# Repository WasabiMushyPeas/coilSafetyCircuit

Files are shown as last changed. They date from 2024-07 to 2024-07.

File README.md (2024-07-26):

# Coil Safety Circuit :electric_plug:

## Introduction :wave:
This safety circuit uses an ESP32 C6 to detect temperature fluctuations or moisture build up on an electromagnet. It can shut off the coils via relay if needed. The ESP32 also hosts a network and webpage to monitor the status of the coils and set the temperature shut off threshold.

## Specifications :clipboard:
- **Power Supply:** USB-C cable to micro controller
- **Max Continuous Coil Power (Each coil):** 65v 5A
- **Max Burst Coil Power:** 65v 35A
- **Pump Power:** 12v 5A
- **Temperature Sensors:** 4 thermistors with an accuracy of ±0.25°C

## Webpage :computer:

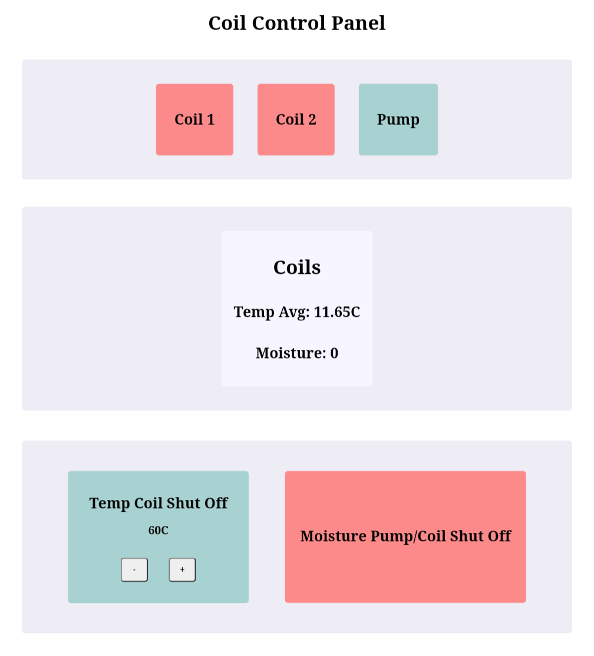
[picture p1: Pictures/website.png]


This picture shows the default settings and appearance of the ESP32 webpage. The user can change the state of the coils and the pump with the three buttons in the top row. If a button is coloured red then that setting or component is off (no relay is open). All coils are off by default and the pump remains on. The user can also turn on and off temperature and moisture shut off with the buttons on the bottom row. It is also possible to change the temperature shut off threshold by clicking the plus or minus buttons on the temperature shut off button until the desired temperature is shown. The middle row show the current temperature average of all the thermistors and whether the moisture sensors are detecting water (0 being to water 1 being water). If the middle row cell is clicked or hovered over it displays more information about the sensors.

:warning: **Warning:** if the ESP32 crashes or loses power everything will be reset to default settings. :warning:

- **Default Settings:** Coils 1 and 2 are off, the pump is on, temperature shut off is on, moisture shut off is off, and the temperature shut off threshold is 60°C.

## Network :satellite:

The webpage can be accessed by connect to the ESP32 network and typing the IP address of the ESP32 into a web browser. The IP address is displayed on the serial monitor when the ESP32 is booting up.

The network name is:
```
ESP32-Access-Point
```

The password is:
```
rydberg12
```

The default IP address is:

```
192.168.4.1
```

## LED Indicators :bulb:
- **Green LED:** Normal operation and coils are off
- **Red LED:** Temperature shut off is active
- **Orange LED:** Moisture shut off is active
- **Blue LED:** Coils are on
- **No LED:** Something is very wrong with the ESP32

## Parts List :moneybag:

| Part | Quantity | Price  |
| --- | --- | --- |
| [ESP32 C6 DEV](https://www.digikey.com/en/products/detail/espressif-systems/ESP32-C6-DEVKITM-1-N4/18667011) | 1 | $8.00  |
| [Thermistor](https://www.digikey.com/en/products/detail/adafruit-industries-llc/4890/13982731) | 4 | $4.75  |
| [Water Sensor](https://www.digikey.com/en/products/detail/adafruit-industries-llc/4965/14302510) | 2 | $3.90  |
| [Coil Relay](https://www.digikey.com/en/products/detail/american-zettler/AZDC007-1AE-12D/22050421) | 2 | $11.78 |
| [Pump Relay](https://www.digikey.com/en/products/detail/american-zettler/AZ943-1CH-12DE/12171590) | 1 | $0.95  |
| [Barrel Connector](https://www.digikey.com/en/products/detail/cui-devices/PJ-037AH/1644547) | 1 | $0.74  |
| [Barrel Connector Cable](https://www.digikey.com/en/products/detail/tensility-international-corp/10-01062/3507709) | 1 | $1.93  |
| [2 Pin Terminal](https://www.digikey.com/en/products/detail/cui-devices/TB002-500-02BE/10064069) | 3 | $1.68  |
| [6 Pin Terminal](https://www.digikey.com/en/products/detail/cui-devices/TB003-500-P06BE/100640891) | 1 | $0.80  |
| [8 Pin Terminal](https://www.digikey.com/en/products/detail/cui-devices/TB001-500-08BE/10064064) | 1 | $1.29  |
| [10k Resistor](https://www.digikey.com/en/products/detail/panasonic-electronic-components/ERA-6AEB103V/1465773) | 10 | $0.99  |
| [DC to DC Converter](https://www.digikey.com/en/products/detail/gaptec-electronic/1S4E-0312S1U/13692037) | 3 | $8.31  |
| [PCB](https://jlcpcb.com/) | 1 | ~$5 |
| Total (without taxes + shipping) | | $49.82 |

## Notes :notebook:

:heavy_exclamation_mark: Some things that need to be done :heavy_exclamation_mark:
- Thermistors need to be calibrated
- Code has not been tested with the PCB yet
- PCB has not been tested yet

Some things that could be added or changed:
- Better website with websockets
- A way to save settings and not reset on power loss
- When connected to the network the control page should pop up automatically using captive portals
- Add a way for ESP32 to get power from the pump power supply
- connect the ESP32 to the lab warning system and trigger when the coils get too hot or wet
- Have the Website accessable out of the lab by having the ESP32 connect to the internet and port forward the website port

## More Information :mag_right:

[Wifi Tutorial](https://randomnerdtutorials.com/esp32-access-point-ap-web-server/)
[Thermistor Tutorial](https://learn.adafruit.com/thermistor/using-a-thermistor)

If you have any questions or suggestions start an issue [here](https://github.com/WasabiMushyPeas/coilSafetyCircuit/issues/new)

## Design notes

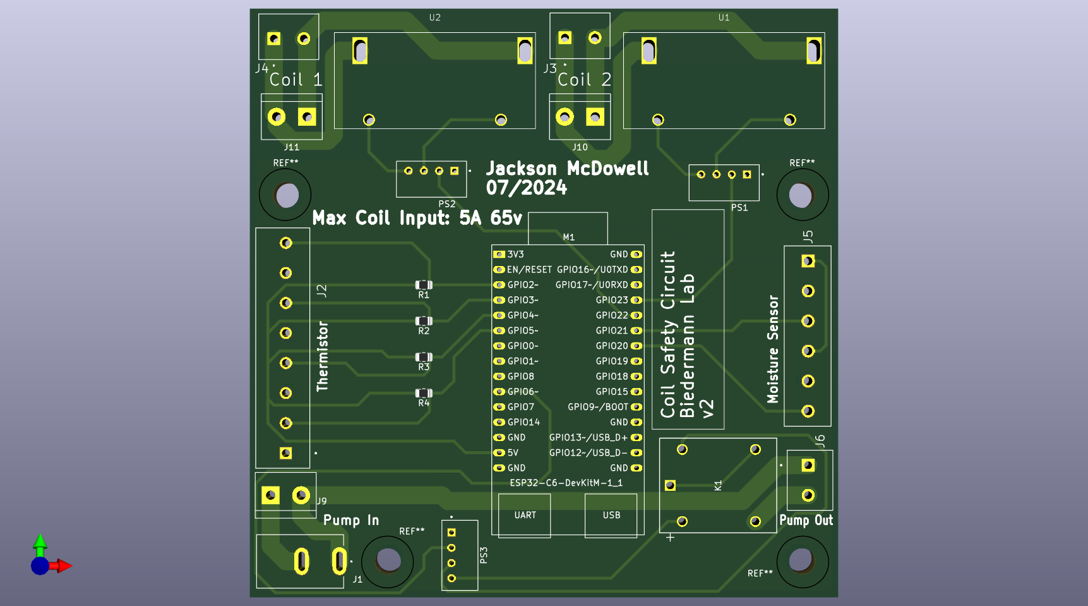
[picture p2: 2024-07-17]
Pictures/frontPCB.png

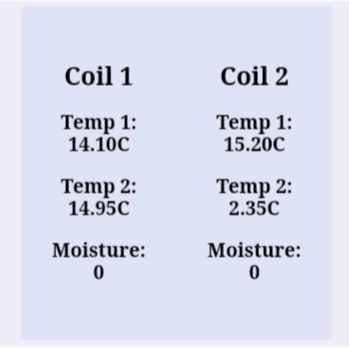
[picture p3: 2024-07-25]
Pictures/websitePOPUP.png

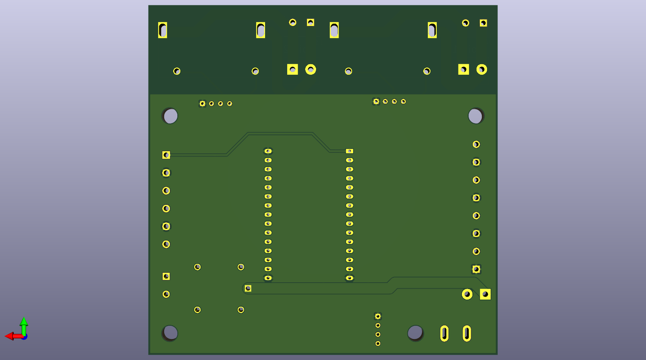
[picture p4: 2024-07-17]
Pictures/backPCB.png

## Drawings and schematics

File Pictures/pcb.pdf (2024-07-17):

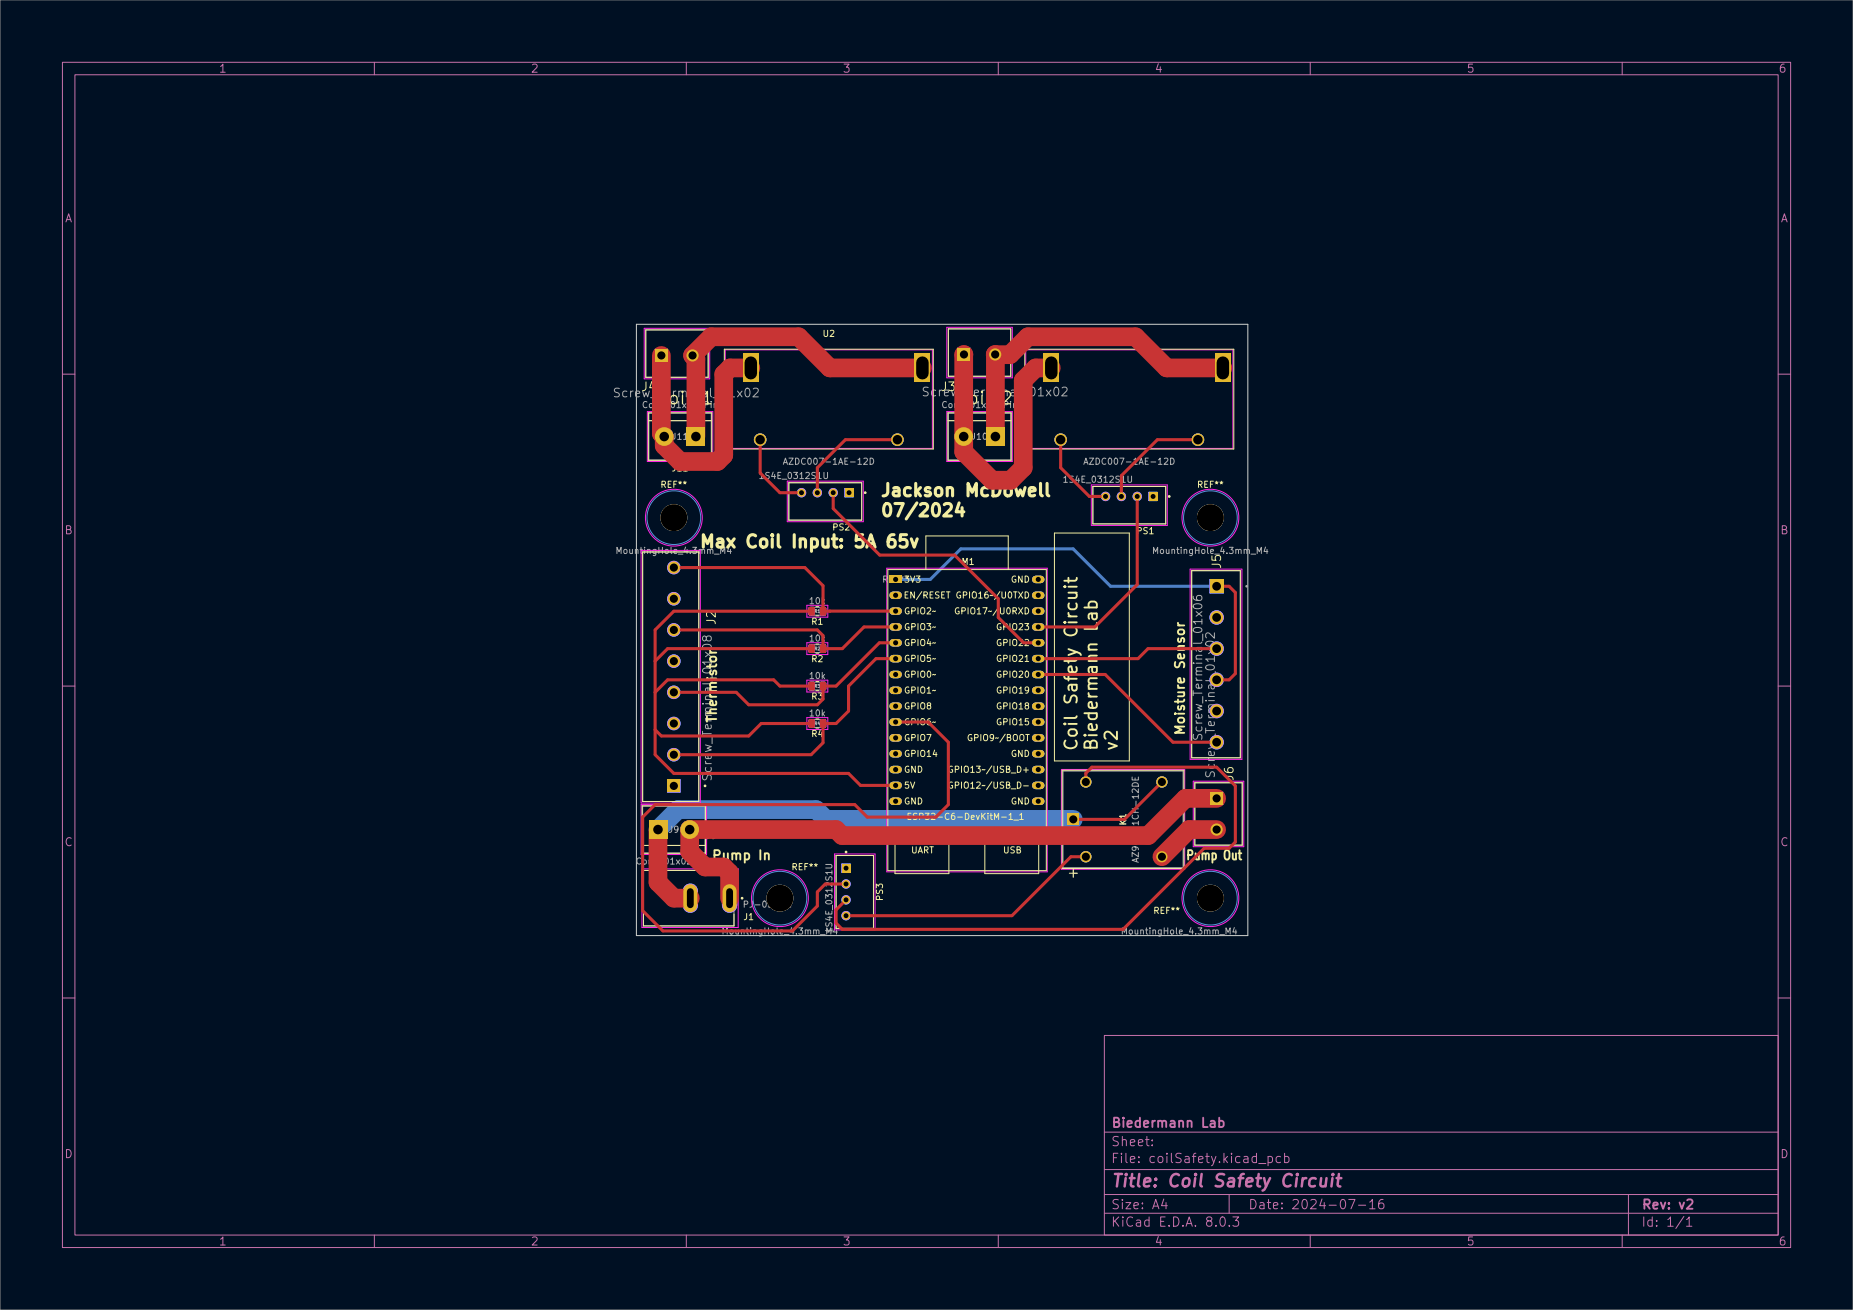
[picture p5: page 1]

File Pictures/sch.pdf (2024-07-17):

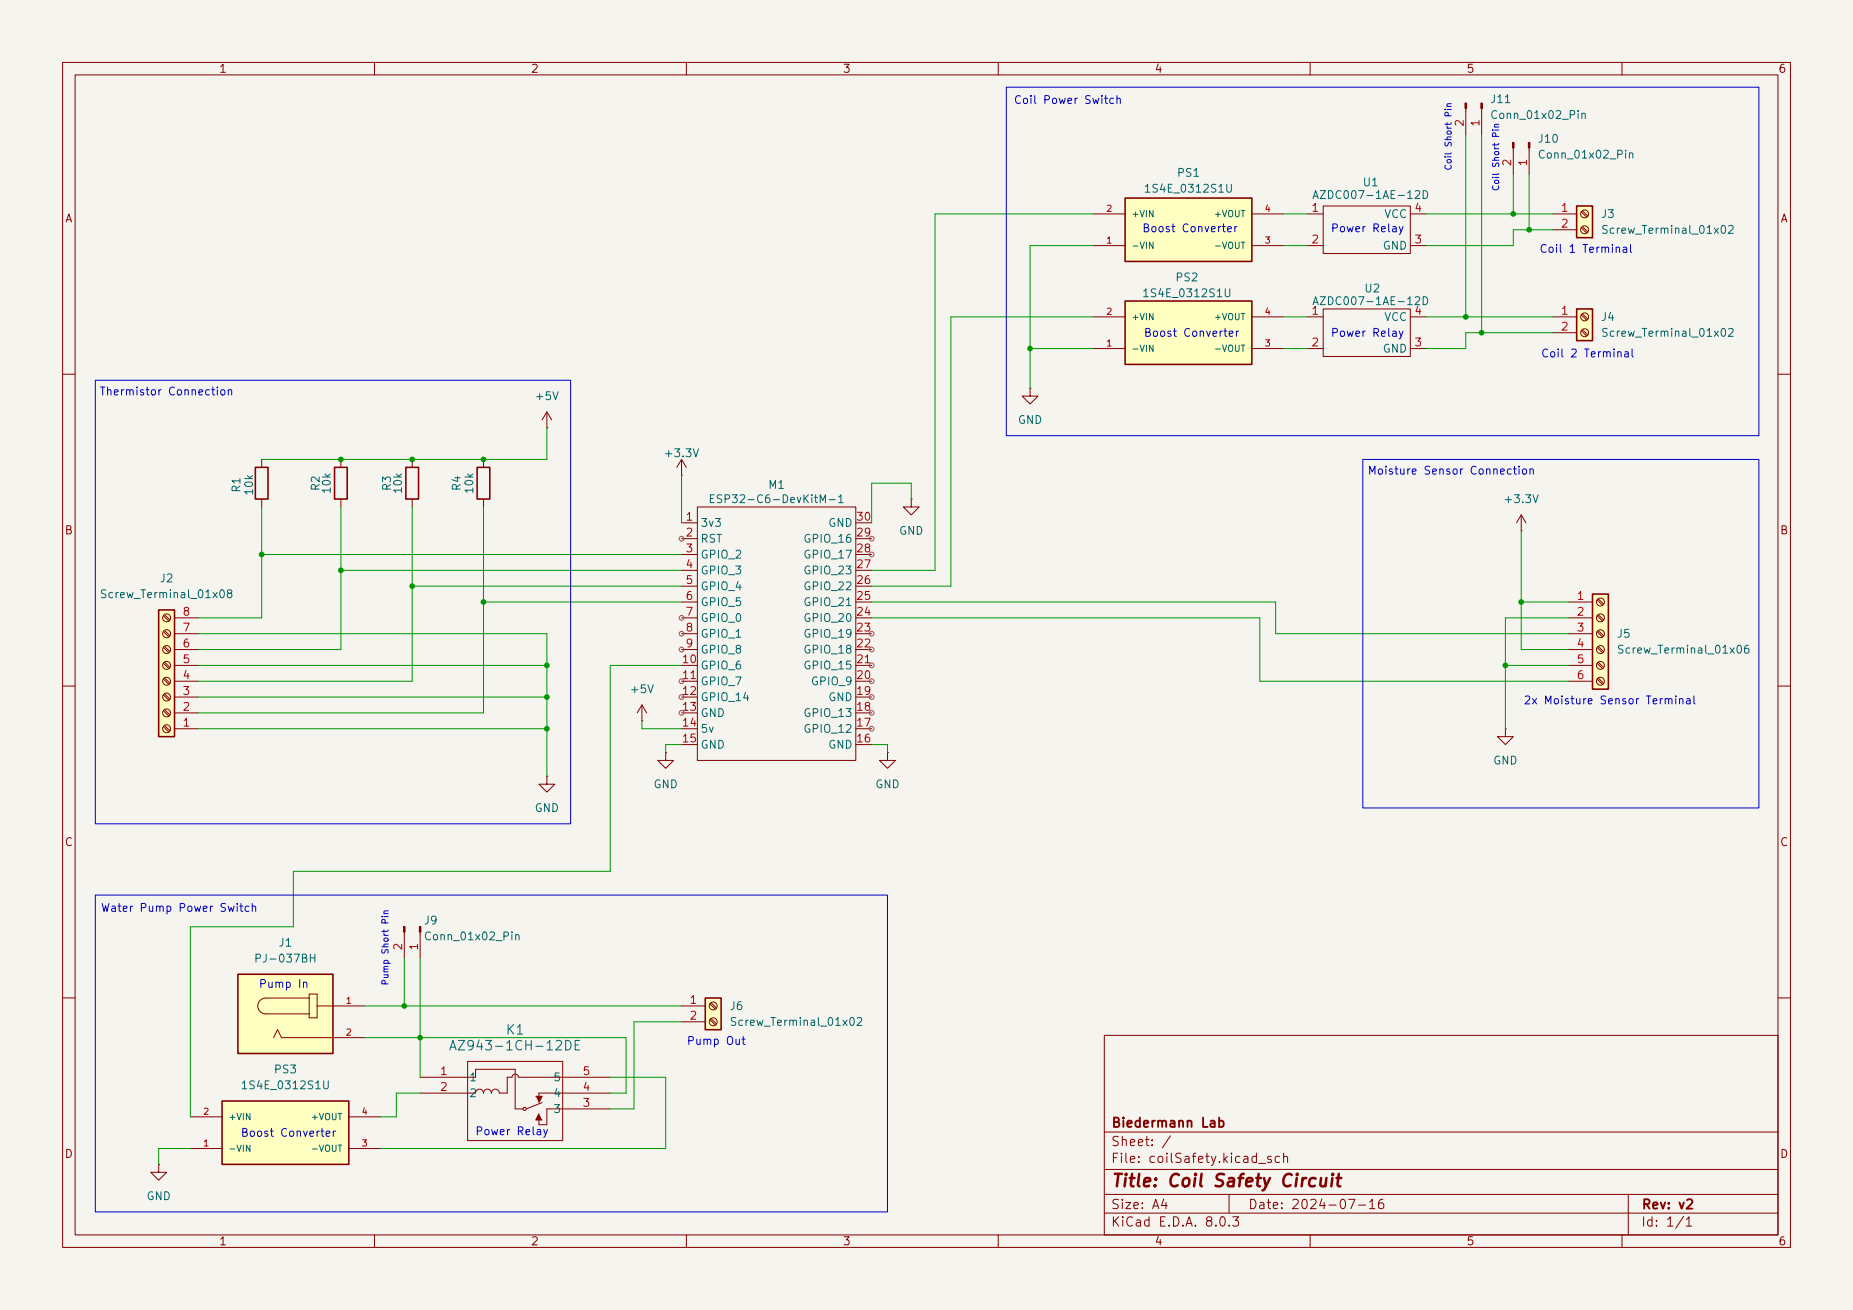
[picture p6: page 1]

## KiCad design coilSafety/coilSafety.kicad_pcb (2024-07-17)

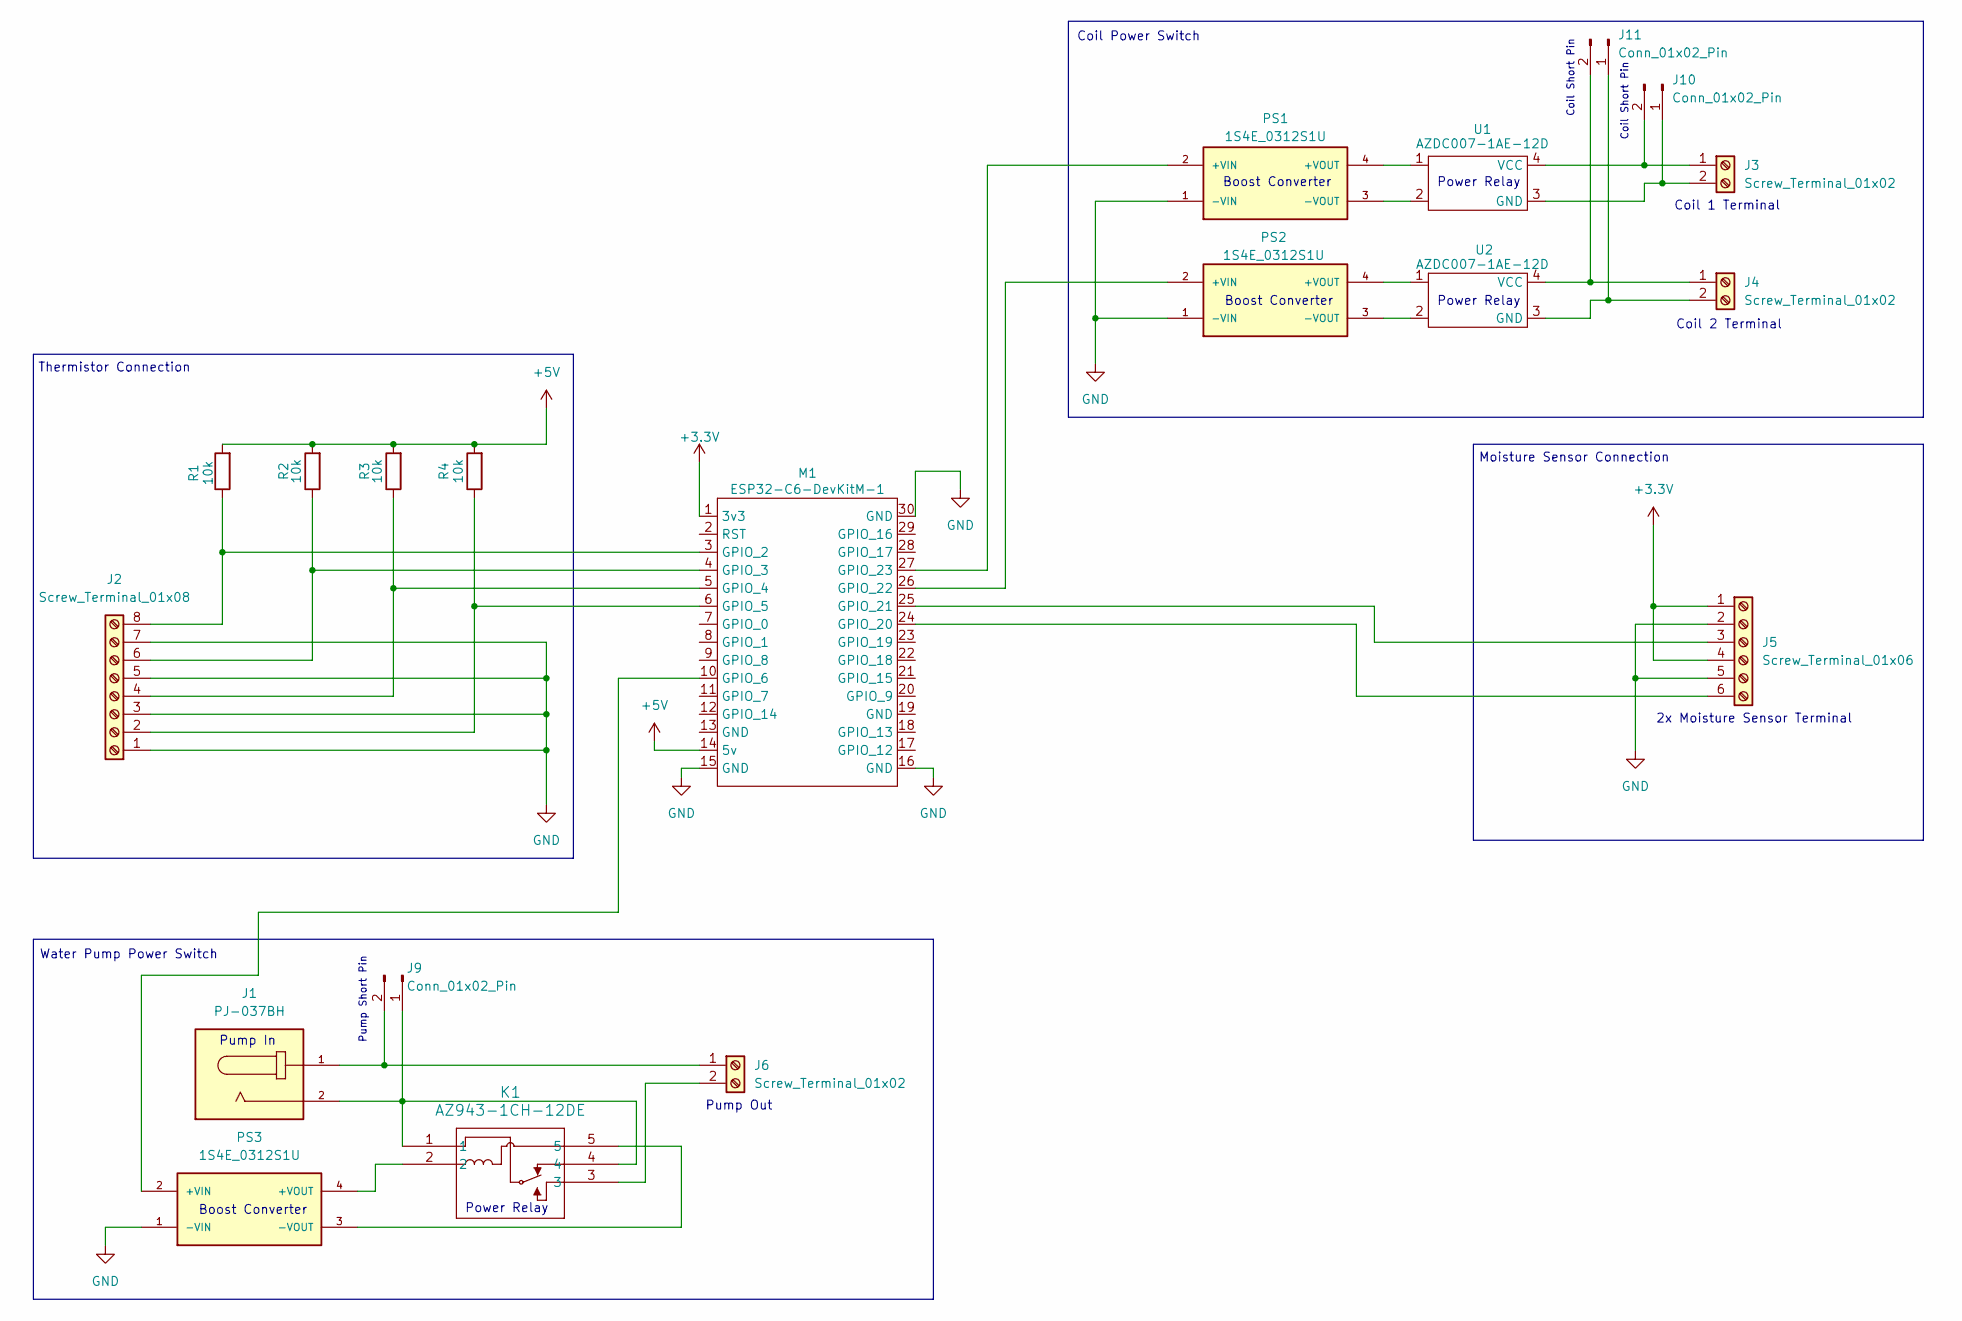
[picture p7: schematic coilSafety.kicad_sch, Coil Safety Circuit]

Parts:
J1: PJ-037BH; CUI_PJ-037BH
J2: Screw_Terminal_01x08; CUI_TB001-500-08BE
J3, J4, J6: Screw_Terminal_01x02; CUI_TB002-500-02BE
J5: Screw_Terminal_01x06; CUI_TB003-500-P06BE
J9, J10, J11: Conn_01x02_Pin; TerminalBlock_bornier-2_P5.08mm
K1: AZ943-1CH-12DE
M1: ESP32-C6-DevKitM-1
PS1, PS2, PS3: 1S4E_0312S1U; CONV_1S4E_0312S1U
R1, R2, R3, R4: 10k; R_0805_2012Metric
U1, U2: AZDC007-1AE-12D

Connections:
+3.3V: J5.1, J5.4, M1.1 (3v3)
+5V: M1.14 (5v), R1.2, R2.2, R3.2, R4.2
GND: J2.1, J2.3, J2.5, J2.7, J5.2, J5.5, M1.15 (GND), M1.16 (GND), M1.30 (GND), PS1.1 (-VIN), PS2.1 (-VIN), PS3.1 (-VIN)
unnamed: J2.2, M1.6 (GPIO_5), R4.1
unnamed: J2.4, M1.5 (GPIO_4), R3.1
unnamed: J2.6, M1.4 (GPIO_3), R2.1
unnamed: J2.8, M1.3 (GPIO_2), R1.1
unnamed: J5.3, M1.25 (GPIO_21)
unnamed: J5.6, M1.24 (GPIO_20)
unnamed: J1.1, J6.1, J9.2
unnamed: J6.2, K1.3
unnamed: J1.2, J9.1, K1.1, K1.4
unnamed: J3.2, J10.1, U1.3 (GND)
unnamed: J3.1, J10.2, U1.4 (VCC)
unnamed: J4.2, J11.1, U2.3 (GND)
unnamed: J4.1, J11.2, U2.4 (VCC)
unnamed: M1.10 (GPIO_6), PS3.2 (+VIN)
unnamed: M1.26 (GPIO_22), PS2.2 (+VIN)
unnamed: M1.27 (GPIO_23), PS1.2 (+VIN)
unnamed: PS1.4 (+VOUT), U1.1
unnamed: PS1.3 (-VOUT), U1.2
unnamed: PS2.4 (+VOUT), U2.1
unnamed: PS2.3 (-VOUT), U2.2
unnamed: K1.2, PS3.4 (+VOUT)
unnamed: K1.5, PS3.3 (-VOUT)

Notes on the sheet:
Coil Short Pin
Coil 1 Terminal
Power Relay
Pump Out
Pump In
Water Pump Power Switch
Coil 2 Terminal
2x Moisture Sensor Terminal
Boost Converter
Pump Short Pin
Coil Power Switch
Moisture Sensor Connection
Thermistor Connection

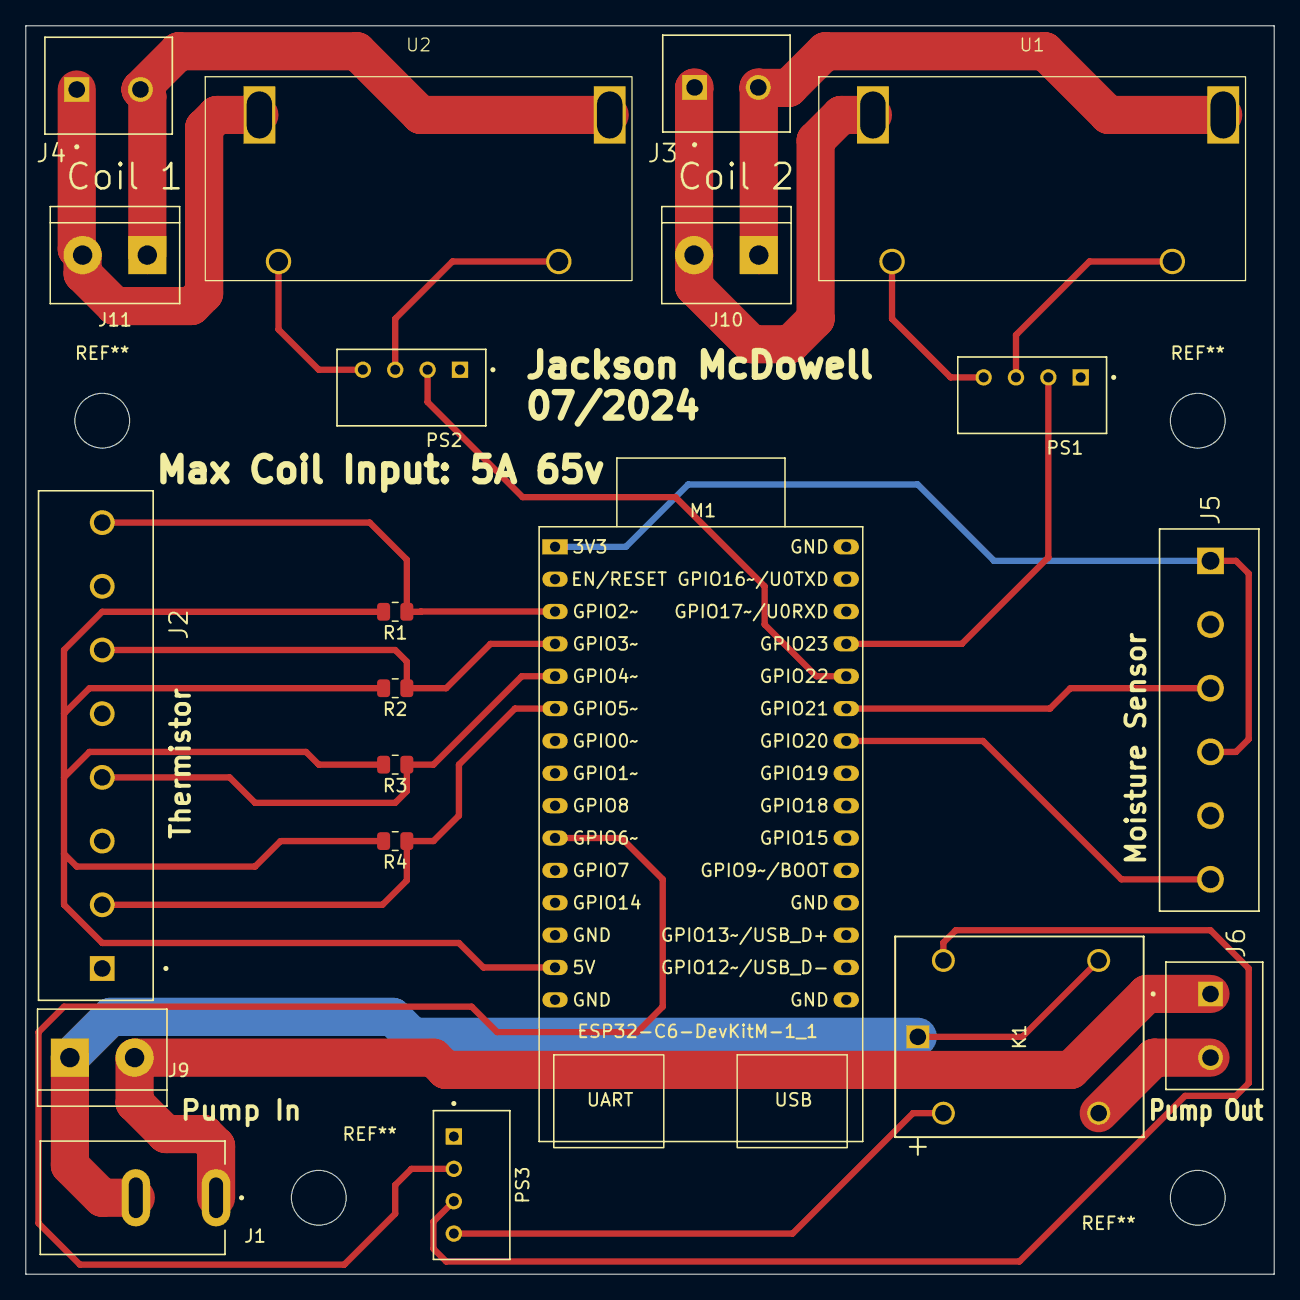
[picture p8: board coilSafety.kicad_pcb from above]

Board: 2 copper layers, 98.0 x 98.0 mm, 20 parts (0 on the bottom side), 25 nets.

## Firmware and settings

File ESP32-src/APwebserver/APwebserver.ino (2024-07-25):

/*
Written By Jackson McDowell for the Biedermann Lab
07/2024

Follow https://randomnerdtutorials.com/esp32-access-point-ap-web-server/ for more information on the WIFI AP Web Server
Follow https://learn.adafruit.com/thermistor/using-a-thermistor for more information on thermistors
*/

#include <WiFi.h>

// Network AP credentials
const char *ssid = "ESP32-Access-Point";
const char *password = "rydberg12";

// Set web server port number to 80
WiFiServer server(80);

// Variable to store the HTTP request
String header;

// Auxiliary variables to store the current output state

// Pump Relay
String output6State = "on";

// Coil Relay
String output22State = "off";
String output23State = "off";
String coilTempShutOff = "on";
String coilPumpMoistureShutOff = "off";

// RGB LED
String outputLEDState = "off";

// LED Error code
String outputErrorState = "none";

// Assign output variables to GPIO pins
const int output6Pump = 6;
const int output22Coil = 22;
const int output23Coil = 23;

// Assign input variables to GPIO pins

// Thermistors
const int input2Thermistor = A2;
const int input3Thermistor = A3;
const int input4Thermistor = A4;
const int input5Thermistor = A5;

// Moisture Sensors
const int input20Moisture = 20;
const int input21Moisture = 21;

// Values
float temp1;
float temp2;
float temp3;
float temp4;
float tempAvg;
int moisture1;
int moisture2;
int moistureTotal;
int coilShutoffTemp = 60;

// Thermistor Variables (Fine tuning may be needed)

// resistance at 25 degrees C
#define THERMISTORNOMINAL 10000
// temp. for nominal resistance (almost always 25 C)
#define TEMPERATURENOMINAL 25
// how many samples to take and average, more takes longer
// but is more 'smooth'
#define NUMSAMPLES 5
// The beta coefficient of the thermistor (usually 3000-4000)
#define BCOEFFICIENT 3950
// the value of the 'other' resistor
#define SERIESRESISTOR 10000

int samples[NUMSAMPLES];

float thermistorTemp(int pin)
{
  uint8_t i;
  float average;

  // take N samples in a row, with a slight delay
  for (i = 0; i < NUMSAMPLES; i++)
  {
    samples[i] = analogRead(pin);
    delay(10);
  }

  // average all the samples out
  average = 0;
  for (i = 0; i < NUMSAMPLES; i++)
  {
    average += samples[i];
  }
  average /= NUMSAMPLES;

  Serial.print("Average analog reading ");
  Serial.println(average);

  // convert the value to resistance
  average = 1023 / average - 1;
  average = SERIESRESISTOR / average;
  Serial.print("Thermistor resistance ");
  Serial.println(average);

  float steinhart;
  steinhart = average / THERMISTORNOMINAL;          // (R/Ro)
  steinhart = log(steinhart);                       // ln(R/Ro)
  steinhart /= BCOEFFICIENT;                        // 1/B * ln(R/Ro)
  steinhart += 1.0 / (TEMPERATURENOMINAL + 273.15); // + (1/To)
  steinhart = 1.0 / steinhart;                      // Invert
  steinhart -= 273.15;                              // convert absolute temp to C

  Serial.print("Temperature ");
  Serial.print(steinhart);
  Serial.println(" *C");

  return steinhart;
}

void setup()
{
  Serial.begin(115200);

  // Initialize the output variables as outputs
  pinMode(output6Pump, OUTPUT);
  pinMode(output22Coil, OUTPUT);
  pinMode(output23Coil, OUTPUT);

  // Initialize the input variables as inputs
  pinMode(input2Thermistor, INPUT);
  pinMode(input3Thermistor, INPUT);
  pinMode(input4Thermistor, INPUT);
  pinMode(input5Thermistor, INPUT);
  pinMode(input20Moisture, INPUT);
  pinMode(input21Moisture, INPUT);

  // Set outputs to LOW
  digitalWrite(output6Pump, HIGH);
  digitalWrite(output22Coil, LOW);
  digitalWrite(output23Coil, LOW);

  // Connect to Wi-Fi network with SSID and password
  Serial.print("Setting AP (Access Point)…");
  // Remove the password parameter, if you want the AP (Access Point) to be open
  WiFi.softAP(ssid, password);

  IPAddress IP = WiFi.softAPIP();
  Serial.print("AP IP address: ");
  Serial.println(IP);

  server.begin();
}

void loop()
{
  outputErrorState = "none";

  temp1 = thermistorTemp(input2Thermistor);
  temp2 = thermistorTemp(input3Thermistor);
  temp3 = thermistorTemp(input4Thermistor);
  temp4 = thermistorTemp(input5Thermistor);

  tempAvg = (temp1 + temp2 + temp3 + temp4) / 4;

  if (digitalRead(input20Moisture) == 1)
  {
    moisture1 = 1;
  }
  else
  {
    moisture1 = 0;
  }

  if (digitalRead(input21Moisture) == 1)
  {
    moisture2 = 1;
  }
  else
  {
    moisture2 = 0;
  }

  if (moisture1 == 1 || moisture2 == 1)
  {
    moistureTotal = 1;
  }
  else
  {
    moistureTotal = 0;
  }

  // Temp Coil Shut Off
  if (coilTempShutOff == "on")
  {
    if (tempAvg >= coilShutoffTemp)
    {
      digitalWrite(output22Coil, LOW);
      digitalWrite(output23Coil, LOW);
      output22Coil = "off";
      output23Coil = "off";
      outputErrorState = "Temp";
    }
  }

  // Pump/Moisture Coil Shut Off
  if (coilPumpMoistureShutOff == "on")
  {
    if (moistureTotal == 1)
    {
      digitalWrite(output6Pump, LOW);
      digitalWrite(output22Coil, LOW);
      digitalWrite(output23Coil, LOW);
      outputErrorState = "Moisture";
    }
  }

  // LED Error Code
  if (outputErrorState == "Temp")
  {
    neopixelWrite(RGB_BUILTIN, RGB_BRIGHTNESS, 0, 0);
  }
  else if (outputErrorState == "Moisture")
  {
    neopixelWrite(RGB_BUILTIN, 255, 94, 0);
  }
  else if (output23State == "on")
  {
    neopixelWrite(RGB_BUILTIN, 0, 0, RGB_BRIGHTNESS);
  }
  else
  {
    neopixelWrite(RGB_BUILTIN, 0, RGB_BRIGHTNESS, 0);
  }

  // Wifi
  WiFiClient client = server.available(); // Listen for incoming clients
  if (client)
  {                                // If a new client connects,
    Serial.println("New Client."); // print a message out in the serial port
    String currentLine = "";       // make a String to hold incoming data from the client
    while (client.connected())
    { // loop while the client's connected
      if (client.available())
      {                         // if there's bytes to read from the client,
        char c = client.read(); // read a byte, then
        Serial.write(c);        // print it out the serial monitor
        header += c;
        if (c == '\n')
        { // if the byte is a newline character
          // if the current line is blank, you got two newline characters in a row.
          // that's the end of the client HTTP request, so send a response:
          if (currentLine.length() == 0)
          {
            // HTTP headers always start with a response code (e.g. HTTP/1.1 200 OK)
            // and a content-type so the client knows what's coming, then a blank line:
            client.println("HTTP/1.1 200 OK");
            client.println("Content-type:text/html");
            client.println("Connection: close");
            client.println();

            // turns the GPIOs on and off
            if (header.indexOf("GET /6/on") >= 0)
            {
              Serial.println("GPIO 6 on");
              output6State = "on";
              digitalWrite(output6Pump, HIGH);
            }
            else if (header.indexOf("GET /6/off") >= 0)
            {
              Serial.println("GPIO 6 off");
              output6State = "off";
              digitalWrite(output6Pump, LOW);
            }
            else if (header.indexOf("GET /22/on") >= 0)
            {
              Serial.println("GPIO 22 on");
              output22State = "on";
              digitalWrite(output22Coil, HIGH);
            }
            else if (header.indexOf("GET /22/off") >= 0)
            {
              Serial.println("GPIO 22 off");
              output22State = "off";
              digitalWrite(output22Coil, LOW);
            }
            else if (header.indexOf("GET /23/on") >= 0)
            {
              Serial.println("GPIO 23 on");
              output23State = "on";
              digitalWrite(output23Coil, HIGH);
            }
            else if (header.indexOf("GET /23/off") >= 0)
            {
              Serial.println("GPIO 23 off");
              output23State = "off";
              digitalWrite(output23Coil, LOW);
            }
            else if (header.indexOf("GET /Temp/on") >= 0)
            {
              Serial.println("Temp Coil Shut Off on");
              coilTempShutOff = "on";
            }
            else if (header.indexOf("GET /Temp/off") >= 0)
            {
              Serial.println("Temp Coil Shut Off off");
              coilTempShutOff = "off";
            }
            else if (header.indexOf("GET /PumpMoisture/on") >= 0)
            {
              Serial.println("Pump/Moisture Coil Shut Off on");
              coilPumpMoistureShutOff = "on";
            }
            else if (header.indexOf("GET /PumpMoisture/off") >= 0)
            {
              Serial.println("Pump/Moisture Coil Shut Off off");
              coilPumpMoistureShutOff = "off";
            }
            else if (header.indexOf("GET /Temp/-") >= 0)
            {
              Serial.println("Temp Coil Shut Off -");
              coilShutoffTemp--;
            }
            else if (header.indexOf("GET /Temp/+") >= 0)
            {
              Serial.println("Temp Coil Shut Off +");
              coilShutoffTemp++;
            }

            client.println("<!DOCTYPE html>");
            client.println("<style> .tooltip { position: relative; display: inline-block; } .tooltip .tooltiptext { visibility: hidden; background-color: #E0E3F4; color: #000; text-align: center; border-radius: 5px; padding: 5px 0; /* Position the tooltip */ position: absolute; z-index: 1; top: -35px; } .tooltip:hover .tooltiptext { visibility: visible; } .tooltip:active .tooltiptext { visibility: visible; } a:hover { scale: 1.1; transition: 0.5s; } </style>");
            client.println("<html lang=\" en \"> <head> <meta charset=\" UTF - 8 \"> <meta name=\" viewport \" content=\" width = device - width, initial - scale = 1.0 \"> <title>Coil Control Panel</title> </head>");
            client.println("<body> <div style=\" text-align : center; display : flex; flex-wrap : wrap; justify-content : center; flex-direction : column; align-items : center; \"> <h1>Coil Control Panel</h1> <div style=\" display : flex; justify-content : center; background-color: #EEECF4; width : 90% ; padding : 20px; border-radius : 5px; margin-top : 20px; margin-bottom : 20px; \">");

            // Display current state, and ON/OFF buttons for GPIO 22
            // If the output22State is off, it displays the ON button
            if (output22State == "off")
            {
              client.println("<a href=\"/22/on\" style=\"text-decoration: none; color: black; \"><div style=\" margin : 20px; background-color: #FD8A8A; padding : 25px; border-radius : 5px; padding-left : 30px; padding-right : 30px; \"> <h2> Coil 1 </h2> </div> </a>");
            }
            else
            {
              client.println("<a href=\"/22/off\" style=\"text-decoration: none; color: black; \"><div style=\" margin : 20px; background-color: #A8D1D1; padding : 25px; border-radius : 5px; padding-left : 30px; padding-right : 30px; \"> <h2> Coil 1 </h2> </div> </a>");
            }

            // Display current state, and ON/OFF buttons for GPIO 23
            // If the output23State is off, it displays the ON button
            if (output23State == "off")
            {
              client.println("<a href=\"/23/on\" style=\"text-decoration: none; color: black; \"><div style=\" margin : 20px; background-color: #FD8A8A; padding : 25px; border-radius : 5px; padding-left : 30px; padding-right : 30px; \"> <h2> Coil 2 </h2> </div> </a>");
            }
            else
            {
              client.println("<a href=\"/23/off\" style=\"text-decoration: none; color: black; \"><div style=\" margin : 20px; background-color: #A8D1D1; padding : 25px; border-radius : 5px; padding-left : 30px; padding-right : 30px; \"> <h2> Coil 2 </h2> </div> </a>");
            }

            // Display current state, and ON/OFF buttons for GPIO 6
            // If the output6State is off, it displays the ON button
            if (output6State == "off")
            {
              client.println("<a href=\"/6/on\" style=\"text-decoration: none; color: black; \"><div style=\" margin : 20px; background-color: #FD8A8A; padding : 25px; border-radius : 5px; padding-left : 30px; padding-right : 30px; \"> <h2> Pump </h2> </div> </a>");
            }
            else
            {
              client.println("<a href=\"/6/off\" style=\"text-decoration: none; color: black; \"><div style=\" margin : 20px; background-color: #A8D1D1; padding : 25px; border-radius : 5px; padding-left : 30px; padding-right : 30px; \"> <h2> Pump </h2> </div> </a>");
            }

            client.println("</div>");

            client.println("<div style=\" display : flex; justify-content : center; flex-wrap : wrap; background-color: #EEECF4; width : 90% ; padding : 20px; border-radius : 5px; margin-top : 25px; margin-bottom : 25px; \"> <div class=\" tooltip \" style=\" display : flex; flex-direction : column; align-items : center; margin : 20px; background-color: #F7F5FF; padding : 20px; border-radius : 5px; \"> <h1>Coils</h1> <h2>Temp Avg: " + String(tempAvg) + "C</h2> <h2>Moisture: " + String(moistureTotal) + "</h2> <span class=\" tooltiptext \"> <div style=\" display : flex; align-items : center; \"> <div style=\" margin : 30px; \"> <h2>Coil 1</h2> <h3>Temp 1: " + String(temp1) + "C</h3> <h3>Temp 2: " + String(temp2) + "C</h3> <h3>Moisture: " + String(moisture1) + "</h3> </div> <div style=\" margin : 30px; \"> <h2>Coil 2</h2> <h3>Temp 1: " + String(temp3) + "C</h3> <h3>Temp 2: " + String(temp4) + "C</h3> <h3>Moisture: " + String(moisture2) + "</h3> </div> </div> </span> </div> </div>");

            client.println("<div style=\"display: flex; justify-content: center; flex-wrap: wrap; background-color: #EEECF4; width: 90%; padding: 20px; border-radius: 5px; margin-top: 25px; margin-bottom: 25px;\">");

            if (coilTempShutOff == "off")
            {
              client.println("<a href=\"/Temp/on\" style=\" text-decoration : none; color: black; \"> <div style=\" margin : 30px; background-color: #FD8A8A; padding : 20px; border-radius : 5px; padding-left : 35px; padding-right : 35px; display : flex; flex-direction : column; align-items : center; \"> <div> <h2>Temp Coil Shut Off</h2> <h3> " + String(coilShutoffTemp) + "C</h3> </div> <div> <a href=\"/Temp/-\" style=\"text-decoration: none; color: black; \"> <button style=\" height : 40px; width : 45px; font - size : 30px; margin : 15px; border-radius : 5px; \">-</button> </a> <a href=\"/Temp/+\" style=\"text-decoration: none; color: black; \"> <button style=\" height : 40px; width : 45px; font - size : 30px; margin : 15px; border-radius : 5px; \">+</button> </a> </div> </div> </a>");
            }
            else
            {
              client.println("<a href=\"/Temp/off\" style=\" text-decoration : none; color: black; \"> <div style=\" margin : 30px; background-color: #A8D1D1; padding : 20px; border-radius : 5px; padding-left : 35px; padding-right : 35px; display : flex; flex-direction : column; align-items : center; \"> <div> <h2>Temp Coil Shut Off</h2> <h3> " + String(coilShutoffTemp) + "C</h3> </div> <div> <a href=\"/Temp/-\" style=\"text-decoration: none; color: black; \"> <button style=\" height : 40px; width : 45px; font - size : 30px; margin : 15px; border-radius : 5px; \">-</button> </a> <a href=\"/Temp/+\" style=\"text-decoration: none; color: black; \"> <button style=\" height : 40px; width : 45px; font - size : 30px; margin : 15px; border-radius : 5px; \">+</button> </a> </div> </div> </a>");
            }

            if (coilPumpMoistureShutOff == "off")
            {
              client.println("<a href=\"/PumpMoisture/on\" style=\"text-decoration: none; color: black; \"> <div style=\" margin : 30px; background-color: #FD8A8A; padding : 75px; border-radius : 5px; padding-left : 25px; padding-right : 25px; display : flex; flex-direction : column; align-items : center; \"> <div> <h2>Moisture Pump/Coil Shut Off</h2> </div> </div> </a>");
            }
            else
            {
              client.println("<a href=\"/PumpMoisture/off\" style=\"text-decoration: none; color: black; \"> <div style=\" margin : 30px; background-color: #A8D1D1; padding : 75px; border-radius : 5px; padding-left : 25px; padding-right : 25px; display : flex; flex-direction : column; align-items : center; \"> <div> <h2>Moisture Pump/Coil Shut Off</h2> </div> </div> </a>");
            }

            client.println("</div></div></body></html>");
            client.println();

            // Break out of the while loop
            break;
          }
          else
          { // if you got a newline, then clear currentLine
            currentLine = "";
          }
        }
        else if (c != '\r')
        {                   // if you got anything else but a carriage return character,
          currentLine += c; // add it to the end of the currentLine
        }
      }
    }
    // Clear the header variable
    header = "";
    // Close the connection
    client.stop();
    Serial.println("Client disconnected.");
    Serial.println("");
  }
}

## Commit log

2024-07-16 Jason's Updates
    [coilSafety.kicad_sch]
2024-07-16 v2 schematic complete
    [coilSafety.kicad_sch]
2024-07-16 Working on PCB
    [coilSafety.kicad_pcb, coilSafety.kicad_sch]
2024-07-17 final commit
    [coilSafety.kicad_pcb]
2024-07-17 fixed trace and text
    [coilSafety.kicad_pcb]
2024-07-17 Update README.md with additional information about the ESP32 C6 and coil monitoring
2024-07-17 Update README.md with coil safety circuit details
2024-07-19 Added ESP32 code
2024-07-19 Add ESP32 web server code with AP functionality
2024-07-19 move AP web server code and add all switches
2024-07-24 Refactor test.html to update moisture pump/coil labels and remove commented code
2024-07-24 chore: Add endpoint handlers for controlling temperature and pump/moisture coils
2024-07-24 feat: Add endpoint handlers for controlling temperature and pump/moisture coils
2024-07-24 chore: Refactor test.html to update moisture pump/coil labels and remove commented code
2024-07-25 feat: Add temperature sensors to parts list
2024-07-25 Update coil shutoff temperature to 65 degrees
2024-07-25 Update default settings and appearance of ESP32 webpage
2024-07-25 Update PCB link in README.md
2024-07-25 chore: Update PCB link, network information, default settings, and appearance of ESP32 webpage
2024-07-25 Update max continuous coil power in README.md
